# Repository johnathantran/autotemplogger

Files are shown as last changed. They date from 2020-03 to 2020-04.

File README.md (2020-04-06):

# autotemplogger
Arduino program to log and timestamp multiple temperatures from DS18B20 sensors to a text file on an SD card. Application for solar collector heat transfer monitoring, although you can use it for any application where you want to automatically record multiple temperatures of different environments.

Reference for Multi-Temperature logging: https://arduinoinfo.mywikis.net/wiki/Brick-Temperature-DS18B20#Multiple_DS18B20_Example

Reference for SD card/temp data integration: https://simple-circuit.com/sd-card-arduino-temperature-data-logger/

The full Arduino circuit diagram is the "Full Circuit Diagram.png" file. Use this to build the circuit.

The final working script is: "autoTempLogger.ino". Upload this script to your Arduino.

When building the final circuit, it is possible to just build the entire circuit right away by following the Full Circuit Diagram provided:

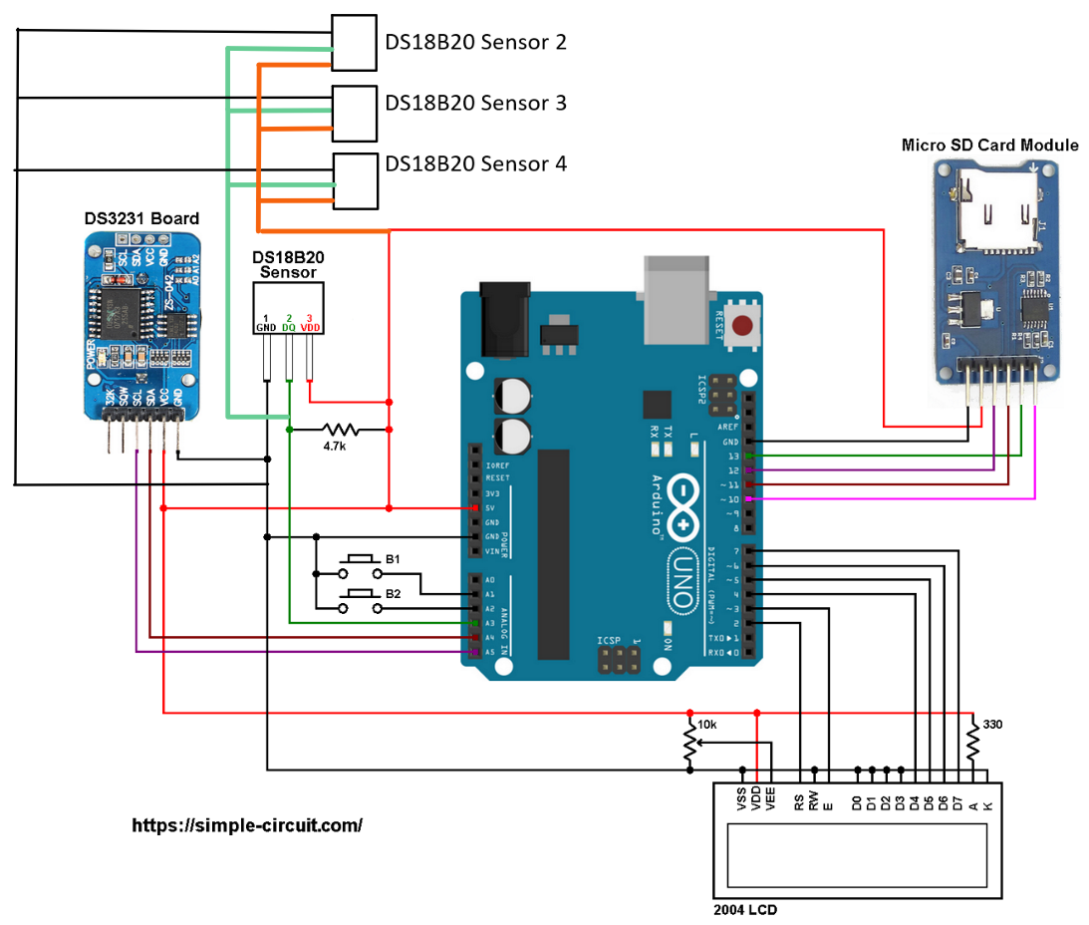
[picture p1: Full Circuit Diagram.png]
Full Wiring Diagram


However, it is best practice to incrementally build the circuit and test if different parts of the circuit work along the way. Therefore I included a few other circuit diagrams and test scripts uploaded in this repo. These are meant for testing purposes, to be used as a reference as the user is building and debugging their circuit from scratch.

In this case, you would build the circuit in order of these steps:
1. Connect LCD Screen
2. Connect First Temperature Sensor 
3. Connect SD card and RTC to Circuit
4. Connect Multiple Temperature Sensors to Circuit

A separate folder is provided for testing and debugging steps 1 and 2. Steps 3 and 4 use the final working script and circuit diagram.

A third folder called "Housing CAD" contains the CAD files created in Solidworks to build the housing of the Arduino system using 1/8-inch laser cut acrylic. The Solidworks files is included for modification, and the PDF file is exported from the Solidworks drawing to be used with the laser cutter.

Finally, a folder for a Python GUI program called "Temperature Analyzer" is included. This program takes the .txt file from the SD card as input, and performs a simple heat transfer analysis on the temperature data to compute heat gain, max temperature, time to reach the max temperature, etc. It then saves the analysis results to a master Excel file called "solarData.xlsx".

After each experiment run with the Arduino, I recommend doing the following:

1. Save your text file on the SD card using the test date as the file name with the format "MM-DD-YYY.txt". This is because the Python program takes the file name as the testing date and records it in the Excel sheet.
2. Run this Python program using the text file as input to easily analyze and record valuable heat transfer data from each experiment. Click "Analyze Data" to perform the heat transfer analysis.
3. Before clicking "Update Master Data", make sure the Excel file "solarData.xlsx" is in the SAME location as the Temperature Analyzer (otherwise it will crash!).
4. Click "Update Master Data" once this is confirmed to update your master Excel file with the calculations.

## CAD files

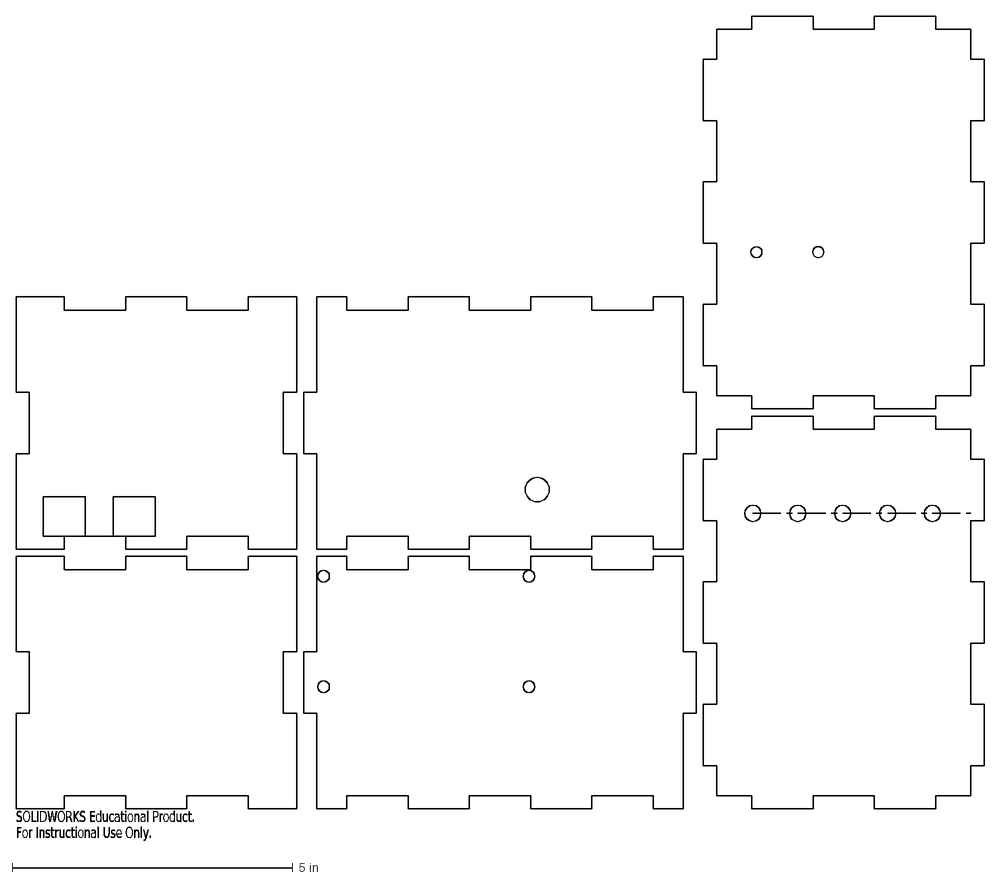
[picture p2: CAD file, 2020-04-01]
Housing CAD/housing.dxf
SOLIDWORKS Educational Product.
For Instructional Use Only.

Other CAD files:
Housing CAD/housing-eights.SLDPRT

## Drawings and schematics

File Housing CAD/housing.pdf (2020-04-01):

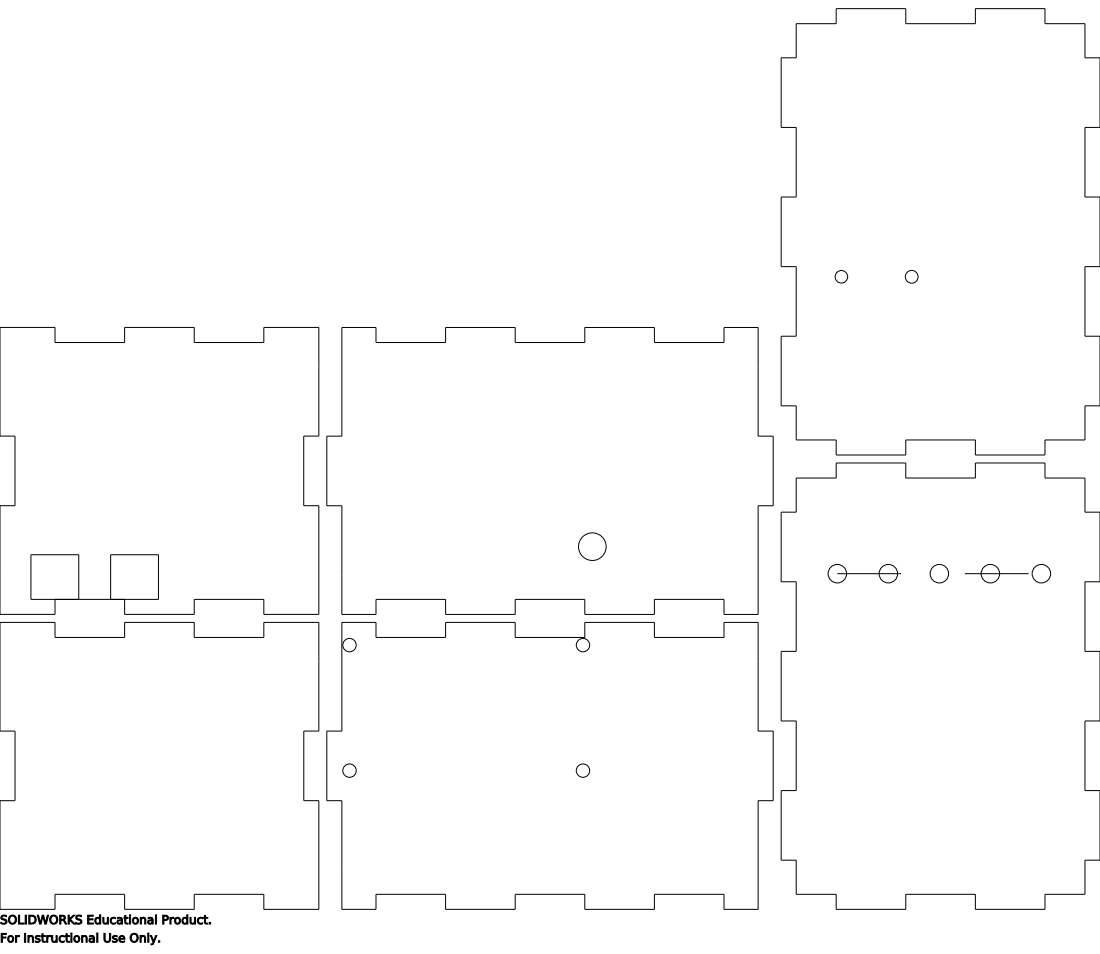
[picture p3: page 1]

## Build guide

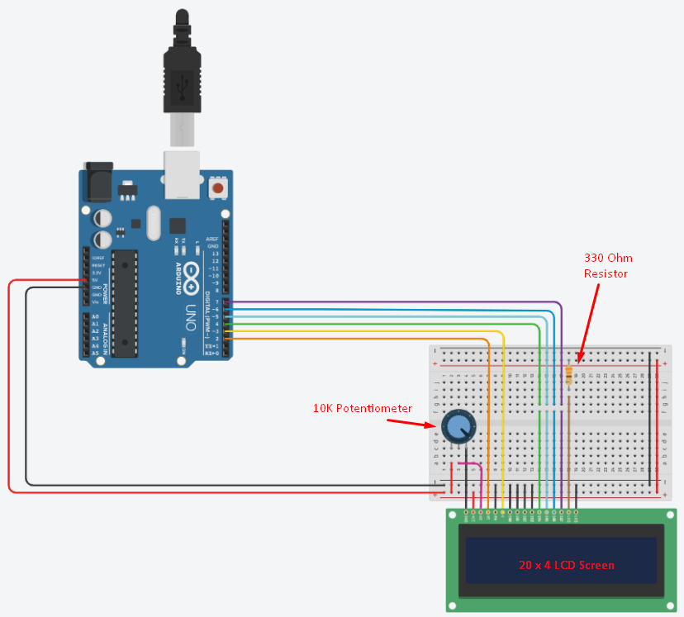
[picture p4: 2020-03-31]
Step One - Connect LCD/1 - Connect LCD.png

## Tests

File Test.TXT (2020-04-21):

    DATE    |    TIME  | TEMP1 | TEMP2 | TEMP3 | TEMP4 |
 10-03-2020 | 01:08:40 | 23.50 | 23.75 | 66.00 | 
 10-03-2020 | 01:08:50 | 23.50 | 23.75 | 26.00 | 
 13-03-2020 | 04:47:30 | 23.50 | 23.25 | 56.00 | 
 13-03-2020 | 04:55:40 | 24.00 | 24.50 | 46.00 | 
 13-03-2020 | 04:56:00 | 24.00 | 24.50 | 85.00 | 
 13-03-2020 | 04:56:20 | 24.00 | 24.50 | 85.00 | 
 13-03-2020 | 04:56:40 | 24.00 | 24.50 | 85.00 | 
 13-03-2020 | 04:57:00 | 24.00 | 24.50 | 85.00 |

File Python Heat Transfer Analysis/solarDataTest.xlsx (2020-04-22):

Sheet: Sheet1
Testing Date | Weather Conditions | Avg Flow Rate [kg/s] | Wind Speed [m/s] | Start Time | Test Duration [hrs] | Min T_a [C] | Max T_a [C] | Significant Test Notes | Max Control Temp [C] | Max Tank Temp [C] | Max Temp Diff [C] | Time to Reach 30C [hrs] | Time to Reach Max Temp [hrs] | Heat Gain to Reach Max Temp [kW]
11-30-2019 | Cloudy Sunny | 0.1 |  | 16:37:00 | 1.333 | 20.4 | 22 |  | 22 | 23.1 | 1.2 | N/A | 0.417 | 0.502
12-01-2019 | Cloudy Sunny | 0.1 |  | 8:55:00 | 5.333 | 9.3 | 26.4 |  | 21.7 | 32.6 | 17.3 | 3.917 | 5.333 | 7.238
10-03-2020 | Cloudy | 0.1 |  | 2020-04-21 01:08 | 3.806 | 26 | 85 |  | 24.5 | 24 | 0.5 | N/A | 3.783 | 0.209
10-03-2020 | Cloudy Sunny | 0.1 |  | 2020-04-21 01:08 | 3.806 | 26 | 85 |  | 24.5 | 24 | 0.5 | N/A | 3.783 | 0.209
10-03-2020 | Cloudy | 0.1 | 3 | 2020-04-21 01:08 | 3.806 | 26 | 85 |  | 24.5 | 24 | 0.5 | N/A | 3.783 | 0.209
10-03-2020 | Cloudy | 3 |  | 2020-04-21 01:08 | 3.806 | 26 | 85 |  | 24.5 | 24 | 0.5 | N/A | 3.783 | 6.276
10-03-2020 | Cloudy | 1 |  | 2020-04-21 01:08 | 3.806 | 26 | 85 |  | 24.5 | 24 | 0.5 | N/A | 3.783 | 2.092
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

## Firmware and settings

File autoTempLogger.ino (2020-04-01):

/* Arduino temperature logger with SD card, DS18B20 sensor and DS3231 (DS1307) RTC.
 * Time, date and temperature are displayed on 20x4 LCD.
 * This is a free software with NO WARRANTY.
 * https://simple-circuit.com/
 */
 
#include <SD.h>               // include Arduino SD library
#include <LiquidCrystal.h>    // include Arduino LCD library
#include <RTClib.h>           // include Adafruit RTC library
#include <OneWire.h>
#include <DallasTemperature.h>

// LCD module connections (RS, E, D4, D5, D6, D7)
LiquidCrystal lcd(2, 3, 4, 5, 6, 7);
 
// initialize RTC library
RTC_DS3231 rtc;
DateTime   now;
 
// buttons definition
#define button1       A1   // button B1 is connected to Arduino pin A1
#define button2       A2   // button B2 is connected to Arduino pin A2
// define DS18B20 data pin
#define ONE_WIRE_BUS A3

// Setup a oneWire instance to communicate with any OneWire device
OneWire oneWire(ONE_WIRE_BUS); 
// Pass oneWire reference to DallasTemperature library
DallasTemperature sensors(&oneWire);
int deviceCount = 0;
float tempC;

File dataLog;
boolean sd_ok = 0;
 
void setup()
{
  sensors.begin();
  // locate devices on the bus
  deviceCount = sensors.getDeviceCount();
  Serial.print(deviceCount, DEC);
  pinMode(button1, INPUT_PULLUP);
  pinMode(button2, INPUT_PULLUP);
 
  rtc.begin();          // initialize RTC chip
  lcd.begin(20, 4);     // initialize LCD module
  lcd.print("T1:");
  //printTemp(0,sensors.getTempCByIndex(0));
  lcd.setCursor(10, 0); // move cursor to column 10, row 0 (first row)
  lcd.print("T2:");
  //printTemp(0,sensors.getTempCByIndex(1));
  lcd.setCursor(0, 3);  // move cursor to column 0, row 3 (last row)
  lcd.print("T3:");
  //printTemp(0,sensors.getTempCByIndex(2));
  lcd.setCursor(10, 3);
  lcd.print("T4:");
  //printTemp(0,sensors.getTempCByIndex(3));
 
  // open serial communications and wait for port to open:
  Serial.begin(9600);
  Serial.print(F("Initializing SD card..."));
 
  // initialize the SD card
  if ( !SD.begin() )
    Serial.println(F("initialization failed!"));  // initialization error
 
  else {   // initialization OK
    sd_ok = 1;
    Serial.println(F("initialization done."));
    if( SD.exists("Log.txt") == 0 )   // test if file with name 'Log.txt' already exists
    {  // create a text file named 'Log.txt'
      Serial.print(F("\r\nCreate 'Log.txt' file ... "));
      dataLog = SD.open("Log.txt", FILE_WRITE);   // create (&open) file Log.txt
      if(dataLog) {                               // if the file opened okay, write to it:
        Serial.println("OK");
        // write some texts to 'Log.txt' file
        dataLog.println(F("    DATE    |    TIME  | TEMP1 | TEMP2 | TEMP3 | TEMP4 |"));
        dataLog.close();   // close the file
      }
      else
        Serial.println("error creating file.");
    }
  }
 
  Serial.println(F("    DATE    |    TIME  | TEMP1 | TEMP2 | TEMP3 | TEMP4 |"));
  Serial.println(F("(dd-mm-yyyy)|(hh:mm:ss)|"));
}
 
// main loop
void loop()
{
  now = rtc.now();  // read current time and date from the RTC chip
  RTC_display();    // diaplay time & calendar
 
  if( !digitalRead(button1) )  // if B1 is pressed
  if( debounce() )             // call debounce function (make sure B1 is pressed)
  {
    while( debounce() );  // call debounce function (wait for B1 to be released)
 
    byte hour   = edit( now.hour() );         // edit hours
    byte minute = edit( now.minute() );       // edit minutes
    byte day    = edit( now.day() );          // edit date
    byte month  = edit( now.month() );        // edit month
    byte year   = edit( now.year() - 2000 );  // edit year
 
    // write time & date data to the RTC chip
    rtc.adjust(DateTime(2000 + year, month, day, hour, minute, 0));
 
    while(debounce());  // call debounce function (wait for button B1 to be released)
  }
 
  static byte p_minute;
  if( (now.minute() % 5 == 0) && (p_minute != now.minute()) )
  {   // read & print temperature value from sensor every 30 seconds

    char buffer2[26];
    bool sensor_ok = 0;
    p_minute = now.minute();
 
    lcd.setCursor(5, 3);
 
    sprintf( buffer2, " %02u-%02u-%04u | %02u:%02u:%02u | ", now.day(), now.month(), now.year(),
                      now.hour(), now.minute(), now.second() );

    // print data on PC serial monitor
    Serial.print(buffer2);

    // write data to SD card
    if(sd_ok)
    {  // if the SD card was successfully initialized
      // open Log.txt file with write permission
      dataLog = SD.open("Log.txt", FILE_WRITE);
      dataLog.print( buffer2 );
    }

    // Send command to all the sensors for temperature conversion
    sensors.requestTemperatures(); 
    
    // Display temperature from each sensor
    for (int i = 0;  i < deviceCount;  i++)
    {
      tempC = sensors.getTempCByIndex(i);
      Serial.print(tempC);
      Serial.print(" | ");
      dataLog.print(tempC);
      dataLog.print(" | ");
      printTemp(i,tempC);  
    }

    dataLog.println("");
    Serial.println("");
    dataLog.close();
 
  }

  delay(100);   // wait 100ms
}

void printTemp(int i,float tempC)
{
  if (i == 0) {
    lcd.setCursor(4,0);
  }
  if (i == 1) {
    lcd.setCursor(14,0);
  }
  if (i == 2) {
    lcd.setCursor(4,3);
  }
  if (i == 3) {
    lcd.setCursor(14,3);
  }
  lcd.print(tempC);
}

//////////////////////////////////////// RTC functions ////////////////////////////////////////
void RTC_display()
{
  char _buffer[17];
  char dow_matrix[7][4] = {"SUN", "MON", "TUE", "WED",
                             "THU", " FRI", "SAT"};
  lcd.setCursor(16,2);
  lcd.print( dow_matrix[now.dayOfTheWeek()] );
 
  // print time
  sprintf( _buffer, "TIME: %02u:%02u:%02u", now.hour(), now.minute(), now.second() );
  lcd.setCursor(0, 1);
  lcd.print(_buffer);
  // print date
  sprintf( _buffer, "DATE: %02u-%02u-%04u", now.day(), now.month(), now.year() );
  lcd.setCursor(0, 2);
  lcd.print(_buffer);
}
 
byte edit(byte parameter)
{
  static byte i = 0, y_pos,
              x_pos[5] = {6, 9, 6, 9, 14};
  char text[3];
  sprintf(text,"%02u", parameter);
 
  if(i < 2)
    y_pos = 1;
  else
    y_pos = 2;
 
  while( debounce() );   // call debounce function (wait for B1 to be released)
 
  while(true) {
    while( !digitalRead(button2) ) {  // while B2 is pressed
      parameter++;
      if(i == 0 && parameter > 23)    // if hours > 23 ==> hours = 0
        parameter = 0;
      if(i == 1 && parameter > 59)    // if minutes > 59 ==> minutes = 0
        parameter = 0;
      if(i == 2 && parameter > 31)    // if day > 31 ==> day = 1
        parameter = 1;
      if(i == 3 && parameter > 12)    // If month > 12 ==> month = 1
        parameter = 1;
      if(i == 4 && parameter > 99)    // If year > 99 ==> year = 0
        parameter = 0;
 
      sprintf(text,"%02u", parameter);
      lcd.setCursor(x_pos[i], y_pos);
      lcd.print(text);
      delay(200);       // wait 200ms
    }
 
    lcd.setCursor(x_pos[i], y_pos);
    lcd.print("  ");
    unsigned long previous_m = millis();
    while( (millis() - previous_m < 250) && digitalRead(button1) && digitalRead(button2) ) ;
    lcd.setCursor(x_pos[i], y_pos);
    lcd.print(text);
    previous_m = millis();
    while( (millis() - previous_m < 250) && digitalRead(button1) && digitalRead(button2) ) ;
 
    if(!digitalRead(button1))
    {                     // if button B1 is pressed
      i = (i + 1) % 5;    // increment 'i' for the next parameter
      return parameter;   // return parameter value and exit
    }
  }
}
 
// a small function for button1 (B1) debounce
bool debounce ()
{
  byte count = 0;
  for(byte i = 0; i < 5; i++)
  {
    if ( !digitalRead(button1) )
      count++;
    delay(10);
  }
 
  if(count > 2)  return 1;
  else           return 0;
}
////////////////////////////////////// end RTC functions //////////////////////////////////////
 

 
// end of code.

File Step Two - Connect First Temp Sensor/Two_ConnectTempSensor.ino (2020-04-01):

/* Arduino temperature logger with SD card, DS18B20 sensor and DS3231 (DS1307) RTC.
 * Time, date and temperature are displayed on 20x4 LCD.
 * This is a free software with NO WARRANTY.
 * https://simple-circuit.com/
 */

#include <OneWire.h>
#include <DallasTemperature.h>
#include <LiquidCrystal.h>

// Data output of DS18B20 is connected to Arduino digital pin 2
#define ONE_WIRE_BUS A3

// Setting a one wire instance
OneWire oneWire(ONE_WIRE_BUS);

// Passing onewire instance to Dallas Temperature sensor library
DallasTemperature sensors(&oneWire);

// LCD module connections (RS, E, D4, D5, D6, D7)
LiquidCrystal lcd(2, 3, 4, 5, 6, 7);
   
void setup(){ 
    lcd.begin(20,4);                       // Initialize the 20x4 LCD shield
    sensors.begin();                        // Begin the DS18B20 initialization
}

void loop(){ 
int Celsius=0, Fahrenheit=0;     // Variables to store temperature readings from DS18B20 temperature sensor
  sensors.requestTemperatures(); // Call all sensors on one wire to start calculating the temperature readings

  Celsius=sensors.getTempCByIndex(0);   //Get temperature reading from sensor 0 in celsius scale
  Fahrenheit=sensors.getTempFByIndex(0);//Get temperature reading from sensor 0 in fahrenheit scale
  
    lcd.setCursor(0, 0);      // Place the lcd cursor on Row-1 Coulomb-1       
    lcd.print("C: ");         // Print Celsius temperature on first row of lcd          
    lcd.print(Celsius); 
    lcd.setCursor(0, 1);      // Place the lcd cursor on Row-2 Coulomb-1      
    lcd.print("F: ");         // Print Fahrenheit temperature on second row of lcd       
    lcd.print(Fahrenheit);      
    delay(5000);              //Refresh the temperature readings after every 5 seconds   
}

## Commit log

2020-03-31 Add files via upload
    Test functionality of a single DS18B20 sensors wired to an Arduino and LCD screen.
2020-04-01 Create solarModel.py
    Python GUI program to perform simple heat transfer analysis on .txt file
2020-04-06 Temperature Analyzer Rev 1
    [solarData.xlsx]
2020-04-21 Added classes
    [solarDataTest.xlsx]
2020-04-22 More robust
    [solarData.xlsx, solarDataTest.xlsx]
